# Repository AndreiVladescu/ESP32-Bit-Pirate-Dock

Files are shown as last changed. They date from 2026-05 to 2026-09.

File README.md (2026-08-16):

<div align="center">

# ESP32-Bit-Pirate-Hardware

<a href="https://github.com/geo-tp/ESP32-Bit-Pirate">
  ESP32 Bit Pirate ecosystem banner
</a>

</div>

**ESP32-Bit-Pirate-Dock** is an open-source carrier board for the Espressif ESP32-S3 DevKit, designed to complement the [ESP32-Bit-Pirate](https://github.com/geo-tp/ESP32-Bit-Pirate) firmware by [geo-tp](https://github.com/geo-tp).

It provides level and voltage translation between the 3.3V ESP32-S3 and external peripherals, with support for **1.8V**, **3.3V**, and **5V** operation. See the [Hardware status](#-hardware-status) section for the current revision, and grab the [fabrication files](#-manufacturing-and-assembly) to build your own.

<div align="center">

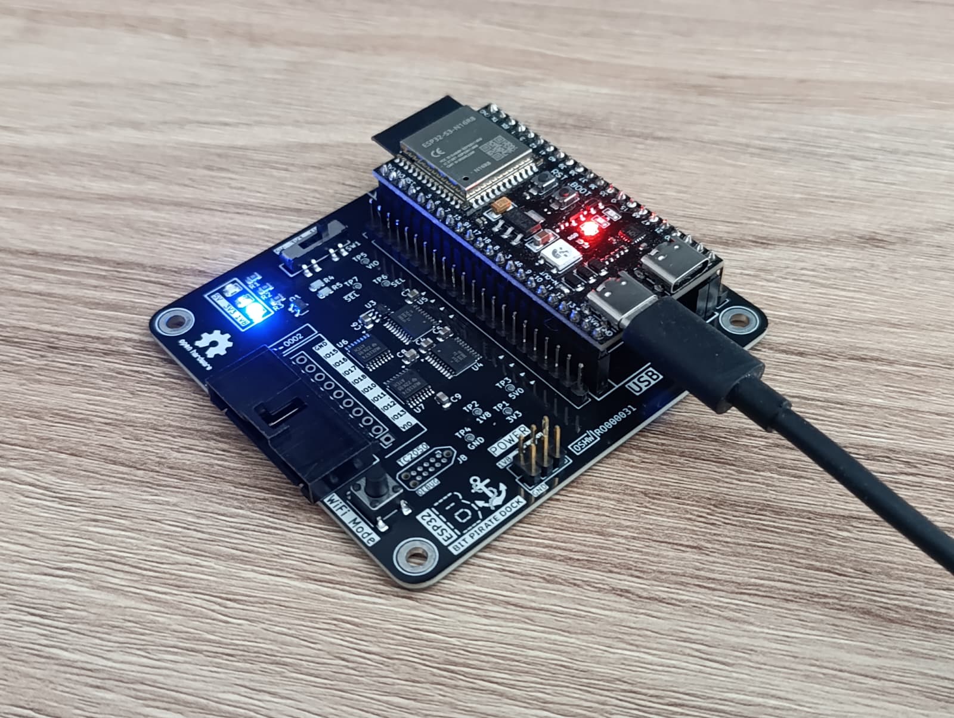
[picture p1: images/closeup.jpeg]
Closeup


</div>

## 🙏 Thanks to PCBWay

A big thank you to [**PCBWay**](https://www.pcbway.com/) for sponsoring and manufacturing the PCBs for this project. Their high-quality fabrication and assembly made bringing this dock to life possible. You can buy the Dock [here](https://www.pcbway.com/project/shareproject/ESP32_Bit_Pirate_Dock_ca02ded7.html) and support the project.

<div align="center">

<a href="https://www.pcbway.com/">
  PCBs manufactured by PCBWay
</a>

</div>

## ✨ Features

- **Level & voltage translation** between the 3.3V ESP32-S3 and external peripherals.
- **Selectable I/O voltage:** 1.8V, 3.3V, and 5V operation.
- **Carrier board** for the original ESP32-S3-DevKitC-1 as well as third-party clones.
- **Designed as a companion** to the [ESP32-Bit-Pirate](https://github.com/geo-tp/ESP32-Bit-Pirate) multi-protocol firmware.
- **Fully open-source hardware** — schematic, PCB layout, gerbers, and BOM included.
- **3D-printable enclosure** — two-piece FDM case provided.

## 📦 Supported Devices

| Device | Notes |
|---|---|
| **ESP32-S3-DevKitC-1** | Genuine Espressif devkit — the reference target for this design. |
| **ESP32-S3 DevKit clones** | Third-party boards work as long as the header pin layout and board dimensions match the official devkit. There is also support for clones which are 2.54mm wider, but you need to measure them to make sure everything will fit|

> [!NOTE]
> This project requires an **ESP32-S3 DevKit to be procured separately by the end user**.

## 🔧 Hardware status

Current hardware revision: **V3**

The markings on the PCB for the serial number `V0-YYWW-XXXXX` are as follows:

- version `0`
- year and week number when these PCBs were produced
- incrementing number of the current batch

An example PCB with these markings would be `V3-2613-00512`, where:

- version number is `3`
- the year is `2026`, and the week is `13`
- this is the `512th` PCB made in that respective week

<div align="center">

Certification mark RO000031

</div>

## 🚀 Getting Started

1. 🛒 **Source an ESP32-S3 DevKit**
   - Buy a genuine board from Espressif or a compatible clone.

2. 🏭 **Fabricate the dock**
   - Send the gerbers in `dock/gerbers/` to your PCB manufacturer of choice.
   - Use `dock/BOM.csv` to source the components for assembly.

3. 🖨️ **Print the enclosure** *(optional)*
   - Print the two-piece case from `dock/3d_models/` on an FDM printer with a 0.4 mm nozzle.

4. 🔌 **Assemble & seat the devkit**
   - Insert the ESP32-S3 DevKit into the headers and select your target I/O voltage (1.8V / 3.3V / 5V).

5. ⚡ **Flash the firmware**
   - Install [ESP32-Bit-Pirate](https://github.com/geo-tp/ESP32-Bit-Pirate) and start probing.

## 📂 Repository contents

- `dock/kicad/` — KiCad design files
- `dock/gerbers/` — PCB fabrication outputs
- `dock/schematic.pdf` — exported schematic reference
- `dock/BOM.csv` — bill of materials
- `dock/3d_models/` — 3D models for the dock and a WIP case
- `c5_adapter/` — KiCad design files for the companion C5 adapter board
- `images/` — presentation images

## 🌐 Open-source scope

This repository open-sources the dock hardware design, including:

- schematic and PCB layout source files
- fabrication outputs
- bill of materials
- project documentation and images included in this repository

## 🧩 Required external parts

This project requires an **ESP32-S3 DevKit to be procured separately by the end user**.

The ESP32-S3 DevKit is a third-party board/module and is **not included** as part of this hardware design repository unless explicitly stated. Vendor silicon, datasheets, trademarks, and separately licensed third-party materials remain the property of their respective owners.

These boards can be acquired through the official Espressif manufacturer and its stores, or through other third-party websites. If not buying a genuine one, make sure the dimensions fit one of the header pins on the board.

## 🛠️ PCB Design

### Top View

<div align="center">

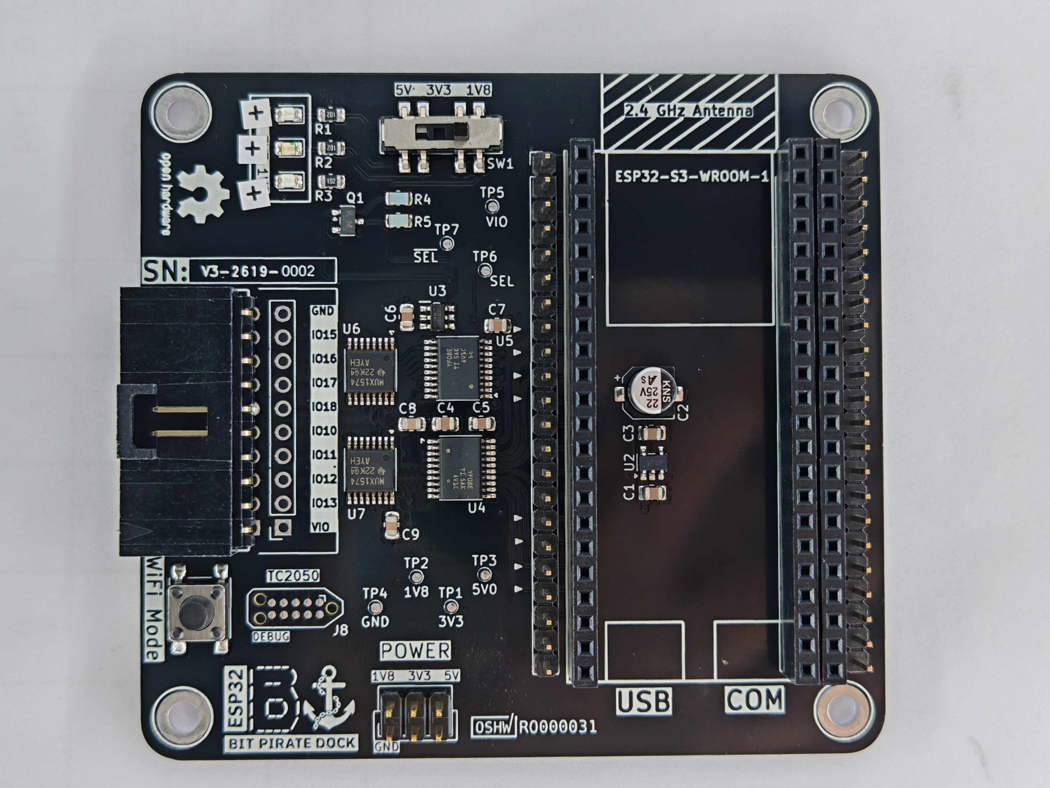
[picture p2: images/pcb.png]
PCB Top


<p>
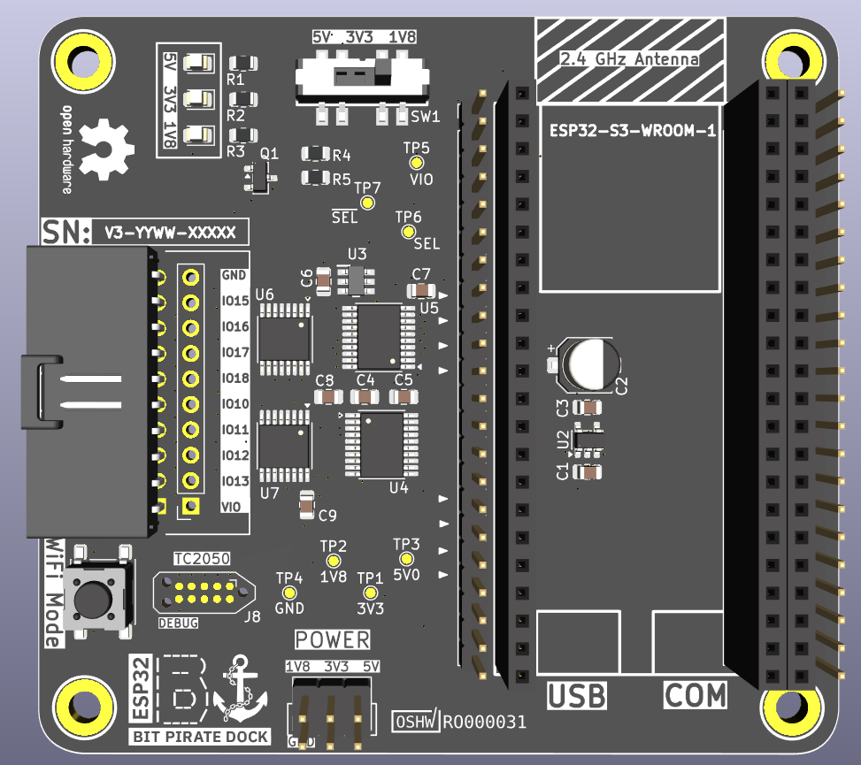
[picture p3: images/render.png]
Front Rendering
  
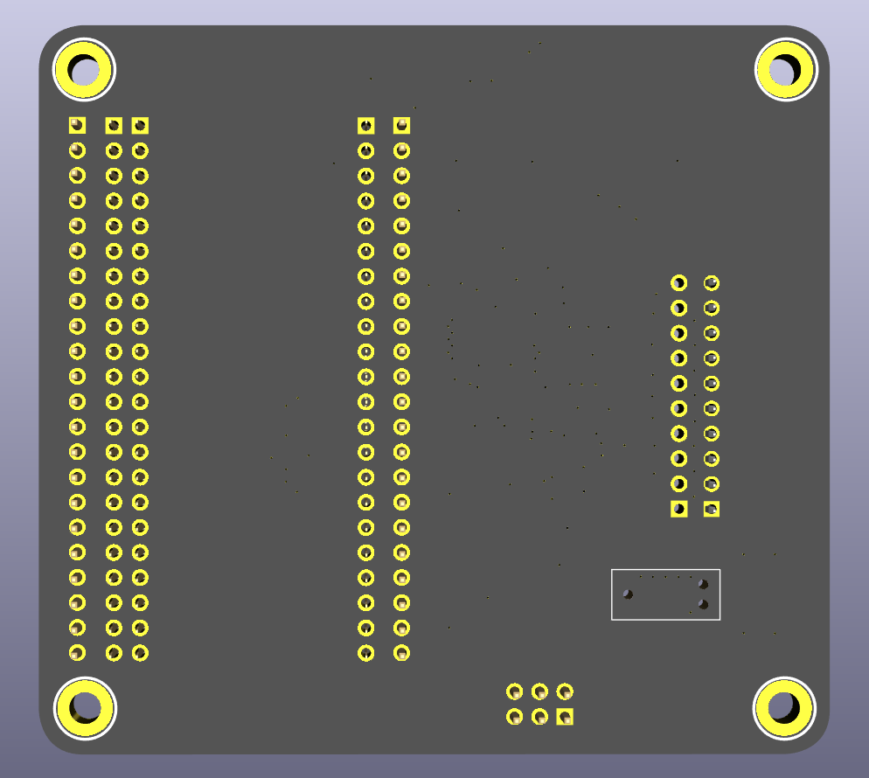
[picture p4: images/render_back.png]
Back Rendering
  
</p>

</div>

## 🏭 Manufacturing and assembly

- To **fabricate the PCB**, use the files in `dock/gerbers/`.
- To **inspect or modify** the design, use the original KiCad source files in `dock/kicad/`.
- To **source components**, use `dock/BOM.csv`.

## 📐 Case Design

The current design uses two pieces, which can be printed using an FDM printer with a 0.4 mm nozzle.

<div align="center">

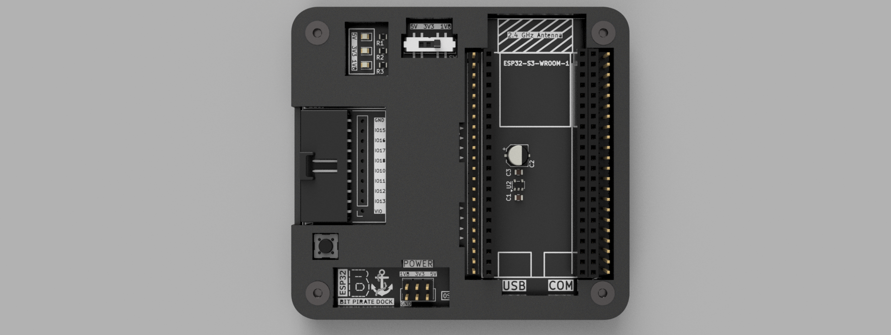
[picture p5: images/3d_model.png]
Case 3D Model


Dock Assembly

</div>

## 🤝 Related Project

This dock is built to complement [**ESP32-Bit-Pirate**](https://github.com/geo-tp/ESP32-Bit-Pirate) by [geo-tp](https://github.com/geo-tp) — an open-source firmware that turns your device into a multi-protocol hacker's tool, inspired by the [Bus Pirate](https://buspirate.com/) project.

## 📜 License

Hardware design files in this repository are licensed under the **CERN-OHL-W-2.0** license. See [LICENSE](LICENSE) for the full license text.

Documentation and images in this repository are licensed under **CC BY 4.0** unless otherwise noted.

Any third-party trademarks, datasheets, and separately licensed materials remain the property of their respective owners.

## ⚠️ Warning

> ⚠️ **Voltage Warning**: External peripherals should only be connected at the **selected translation voltage** (**1.8V**, **3.3V**, or **5V**).
>
> *   Do **not** connect peripherals using other voltage levels — doing so may **damage your ESP32 or the dock**.
> *   Always confirm the selected I/O voltage before powering up connected hardware.
>

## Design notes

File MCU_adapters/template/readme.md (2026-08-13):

Template directory
==================

# Installation

- Copy the **templateAdapters** directory in your **KICAD_USER_TEMPLATE_DIR**
- It will then be displayed in the template list when you create a new project (The template is easy to identify with the Bit Pirate logo).

# How to use
## The schematic
The schematic is divided in 3 parts
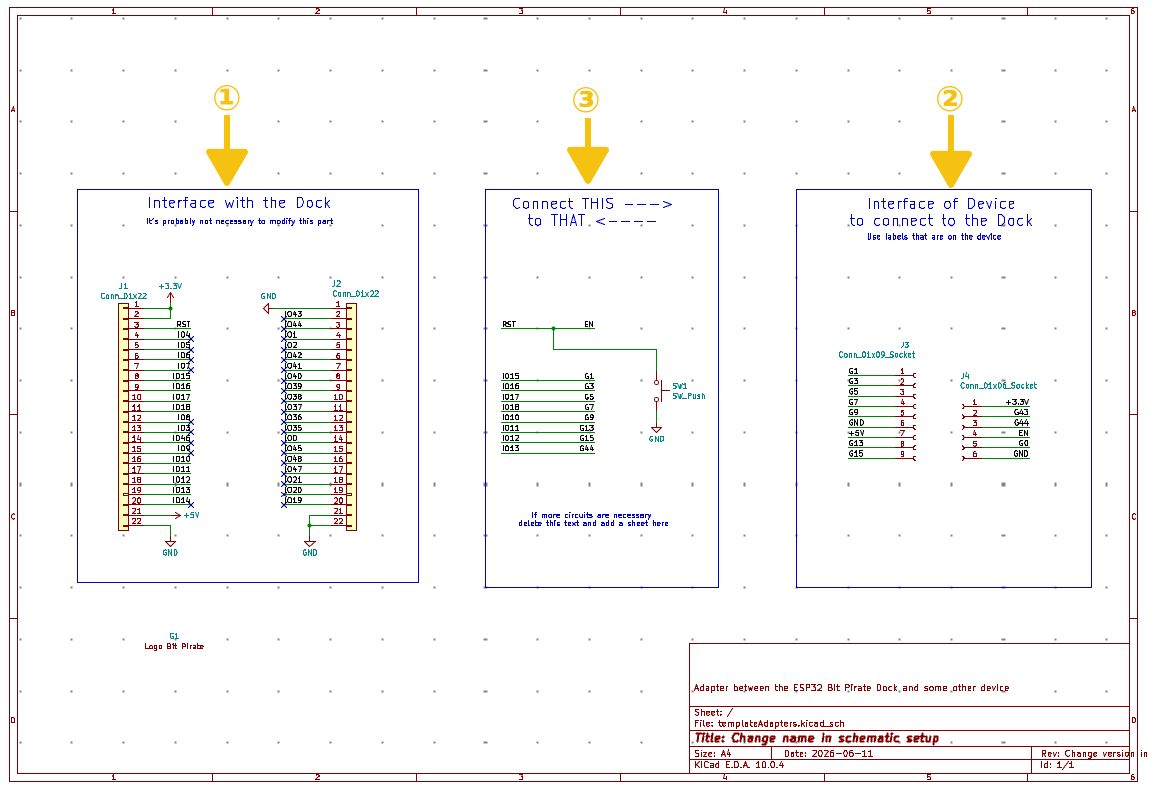
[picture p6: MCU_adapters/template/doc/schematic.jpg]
schematic


1. this part is the interface with the dock. It shows all the IOs that the are exposed to the adapter. By default all the IOs but the 8 ones that are routed to the outside of the dock and the power supplies are tagged as not used. This part is not supposed to be modified.
2. this part is the interface of the device to be connected to the Dock. All the necessary connectors must be added and it is recommanded to use the same label for the IOs as the one used in the device documentation (as long as there is no conflict with the labels of the Dock).
3. this part describes the connexion between the device and the Dock. A least, this part must displays wich IO of the device connects to which IO of the Dock. If some hardware is to be added, it can be drawn in this part or an external sheet can be added in case it is too bulky.

The name of the board and the version number can be changed in Files/Schematic Setup/Text Variables. Their values will be paste to the PCB.  
After the text variables are modified you must: save the schematic, update the PCB, save the PCB, close the PCB, reopen the PCB, the name and version must now be up to date.

## The PCB
By default the PCB is the size of the ESP32-S3 devkit and J1-J2 connectors are locked in place so they will have the right spacing and position.

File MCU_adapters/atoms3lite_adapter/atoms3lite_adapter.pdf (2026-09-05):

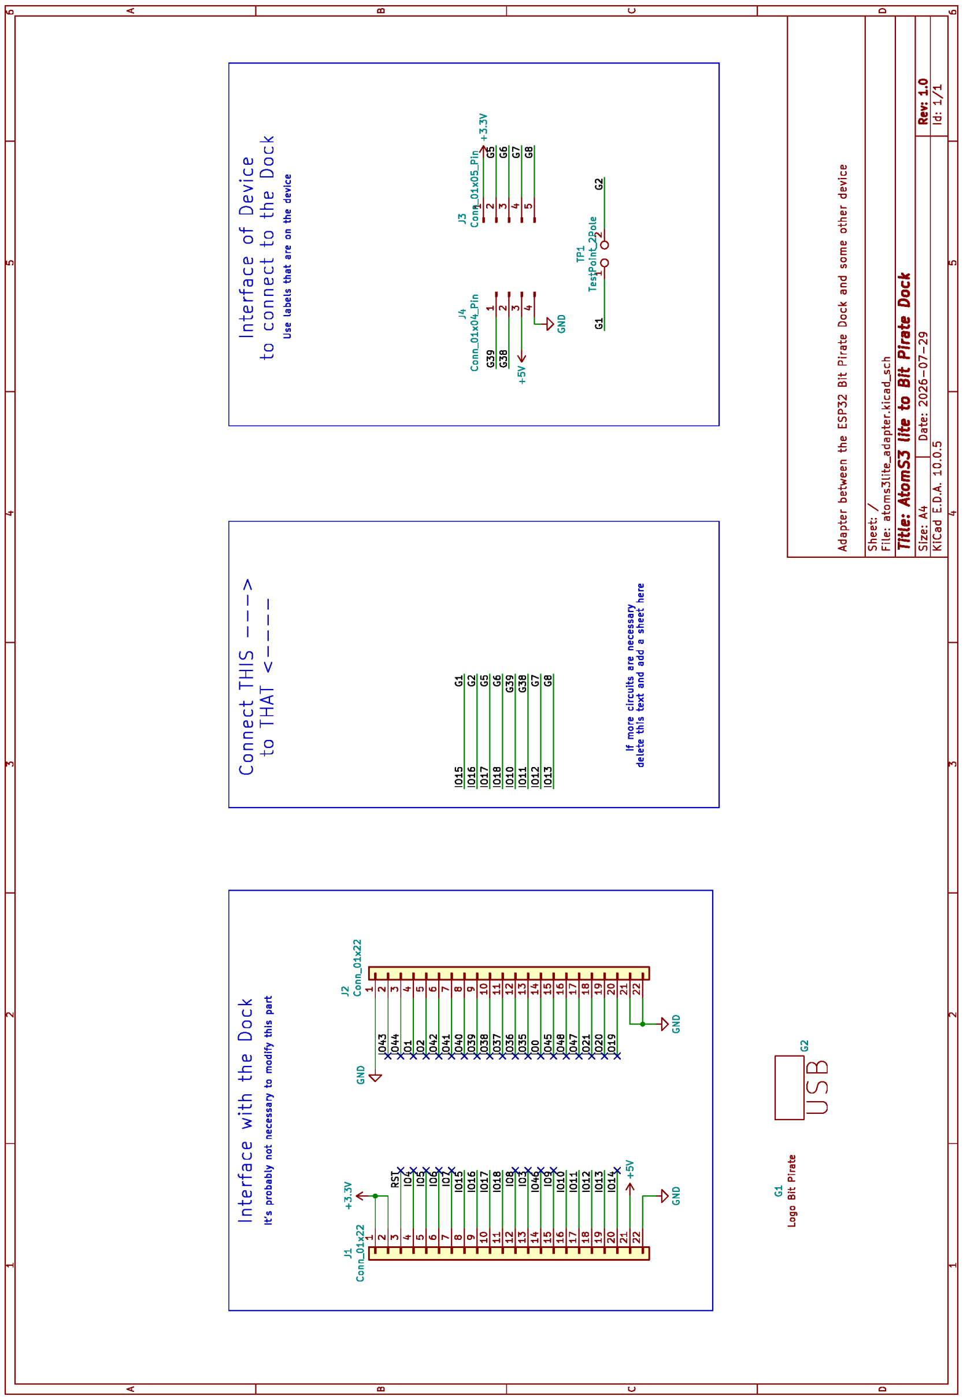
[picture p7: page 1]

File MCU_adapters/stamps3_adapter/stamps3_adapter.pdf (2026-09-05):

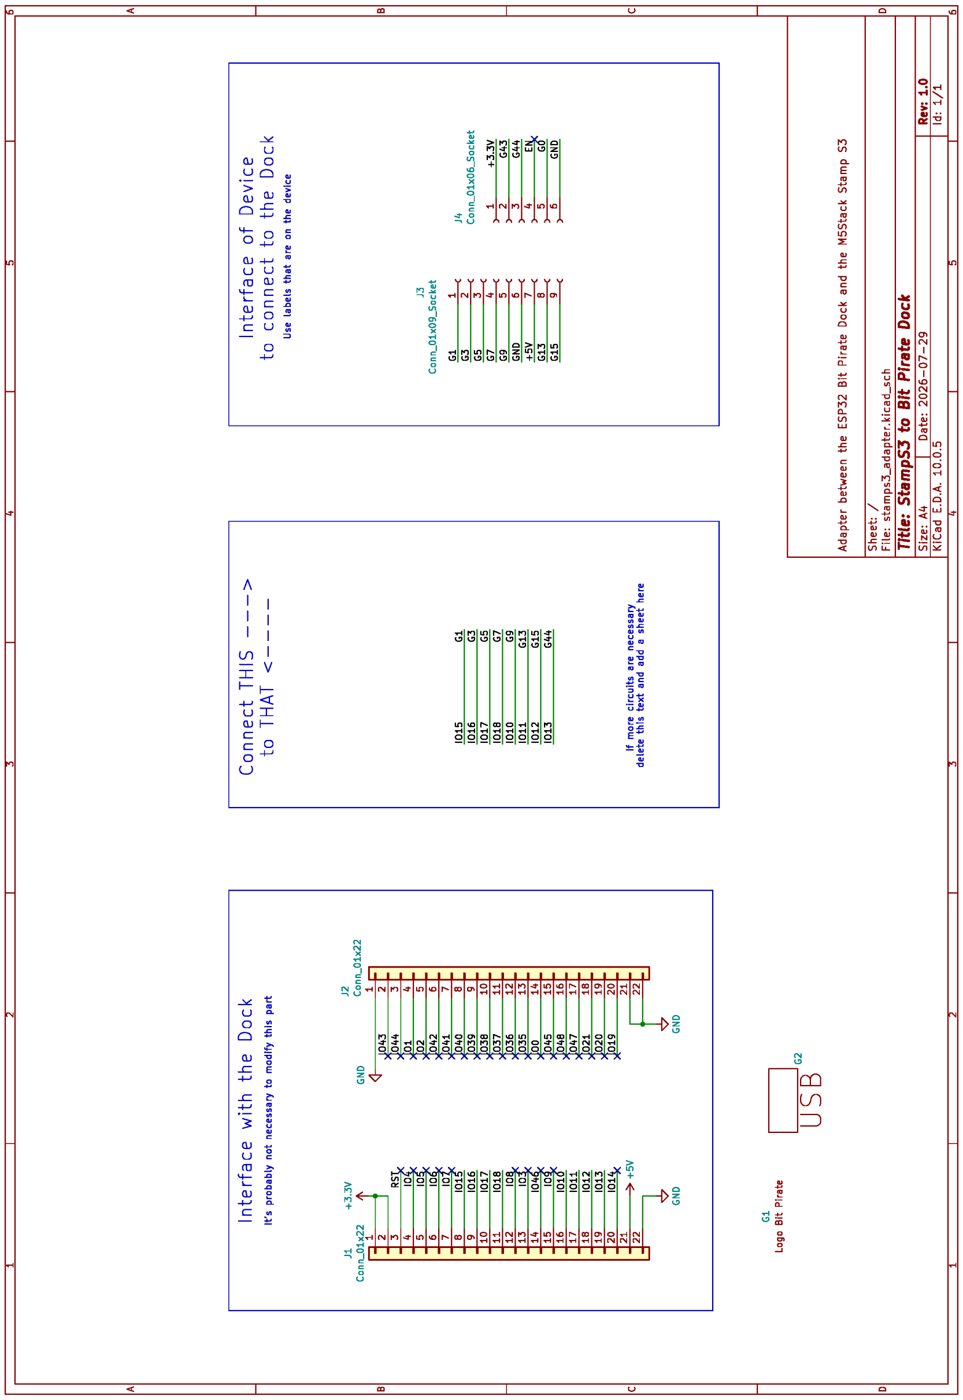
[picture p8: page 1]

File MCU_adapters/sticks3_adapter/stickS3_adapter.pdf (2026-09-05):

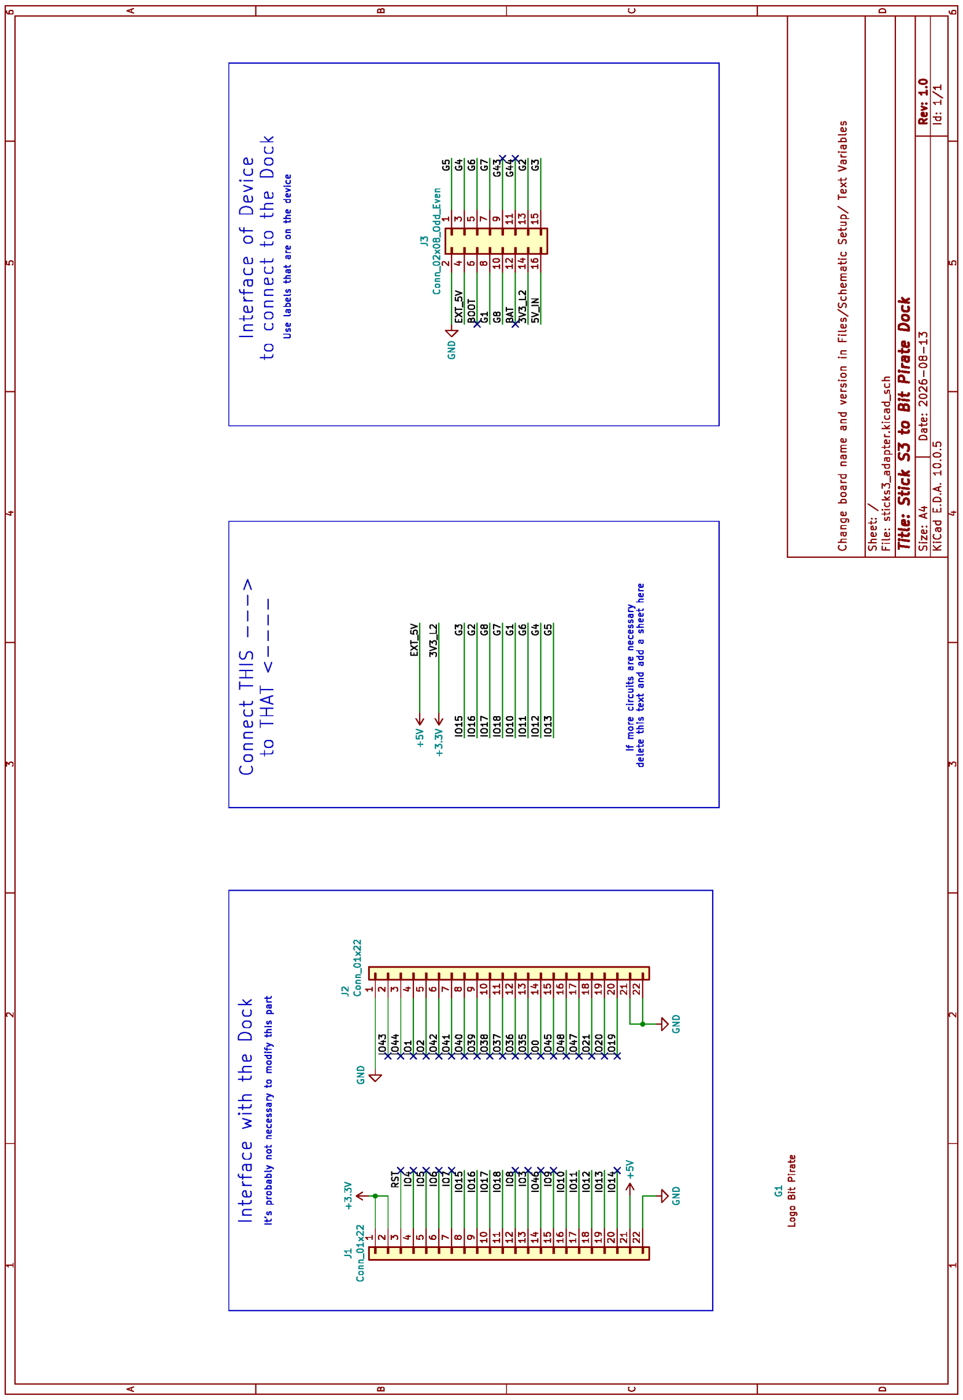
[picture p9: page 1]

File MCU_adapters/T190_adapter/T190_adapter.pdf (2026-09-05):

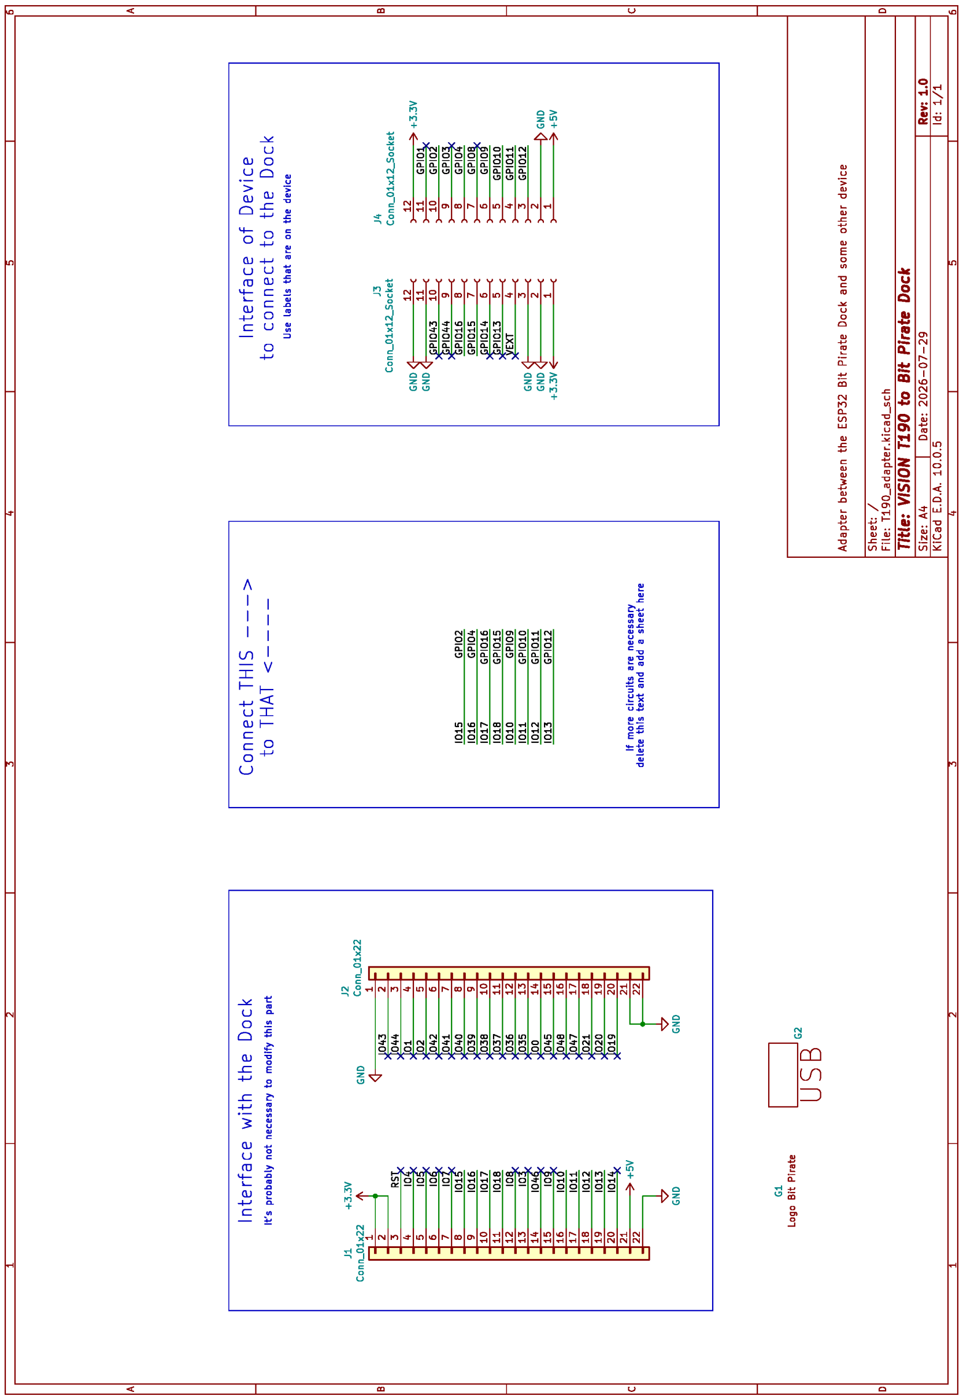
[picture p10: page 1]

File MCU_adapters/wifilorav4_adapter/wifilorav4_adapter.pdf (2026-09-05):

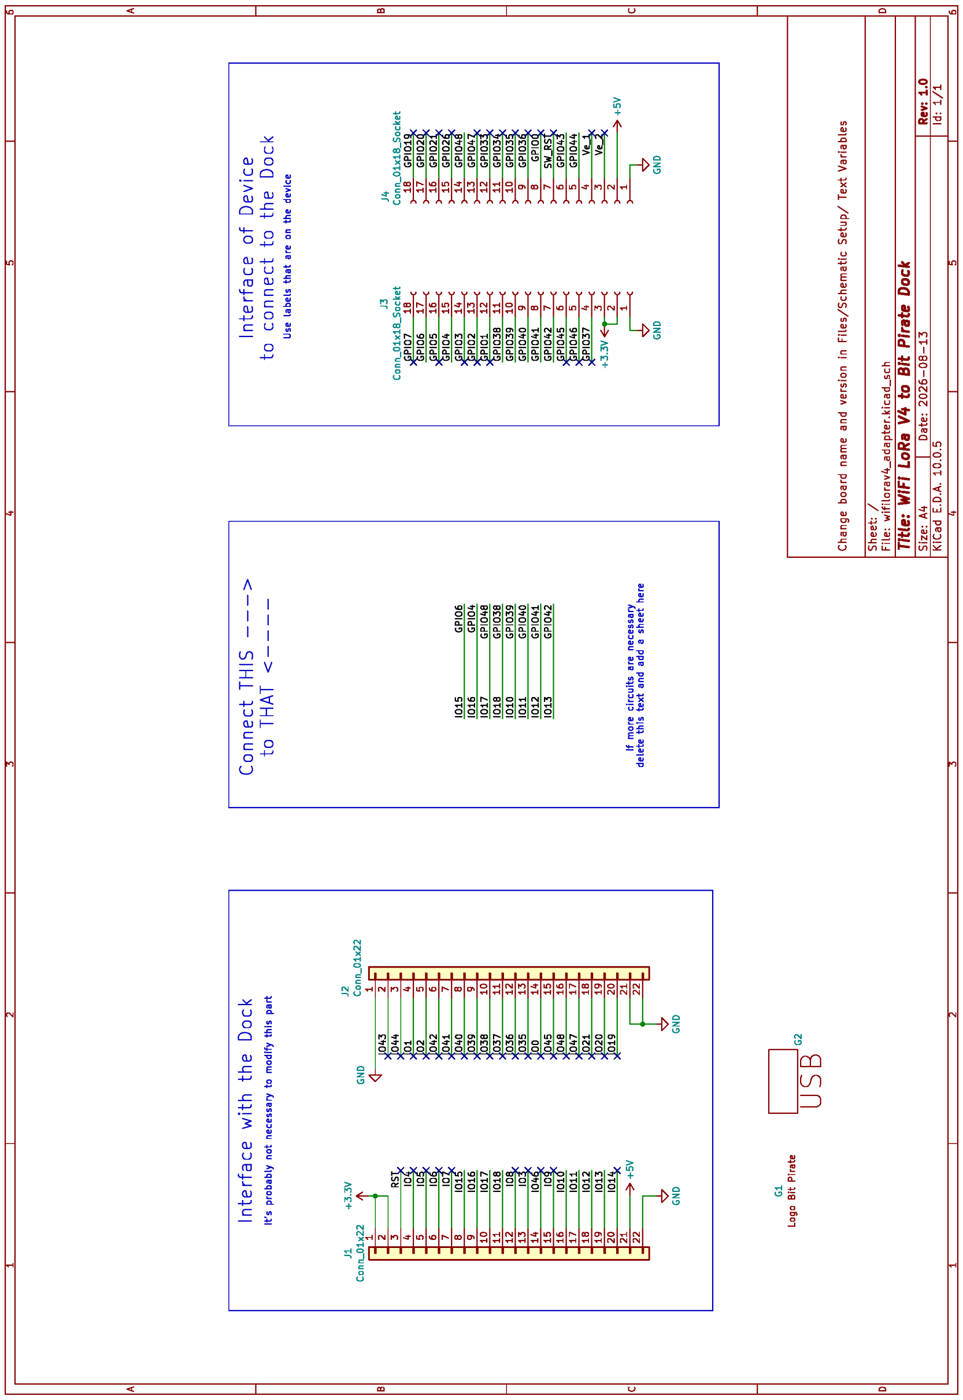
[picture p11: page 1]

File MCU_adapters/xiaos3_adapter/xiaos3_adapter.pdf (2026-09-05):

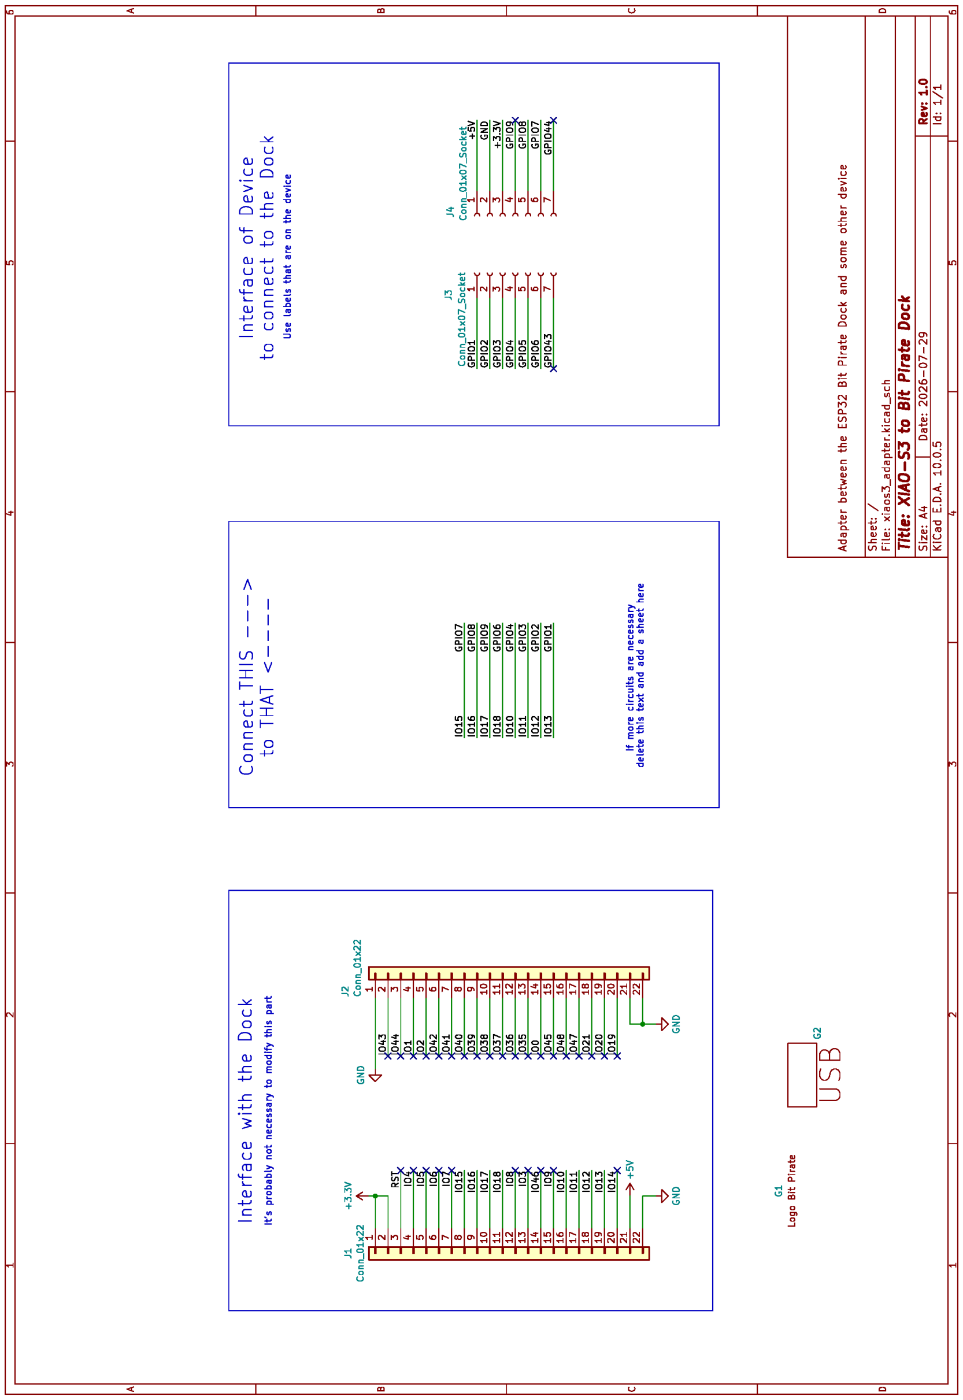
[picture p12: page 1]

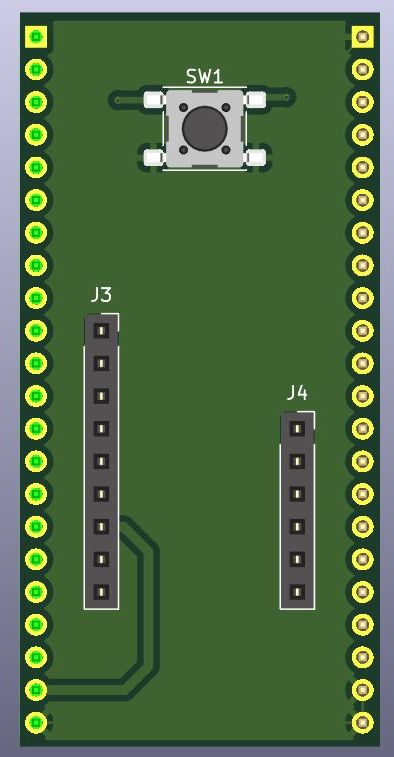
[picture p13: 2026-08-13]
MCU_adapters/template/templateAdapters/meta/board.jpg

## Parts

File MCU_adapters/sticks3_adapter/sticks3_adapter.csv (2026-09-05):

Reference | Qty | Value | DNP | Exclude from BOM | Exclude from Board | Footprint | Datasheet
G1 | 1 |  |  |  |  | logo:logoBP
J1,J2 | 2 | Conn_01x22 |  |  |  | Connector_PinHeader_2.54mm:PinHeader_1x22_P2.54mm_Vertical
J3 | 1 | Conn_02x08_Odd_Even |  |  |  | Connector_PinHeader_2.54mm:PinHeader_2x08_P2.54mm_Horizontal

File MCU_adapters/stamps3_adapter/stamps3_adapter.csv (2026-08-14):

Reference | Qty | Value | DNP | Exclude from BOM | Exclude from Board | Footprint | Datasheet
G1 | 1 |  |  |  |  | logo:logoBP
J1,J2 | 2 | Conn_01x22 |  |  |  | Connector_PinHeader_2.54mm:PinHeader_1x22_P2.54mm_Vertical
J3 | 1 | Conn_01x09_Socket |  |  |  | Connector_PinSocket_2.54mm:PinSocket_1x09_P2.54mm_Vertical
J4 | 1 | Conn_01x06_Socket |  |  |  | Connector_PinSocket_2.54mm:PinSocket_1x06_P2.54mm_Vertical

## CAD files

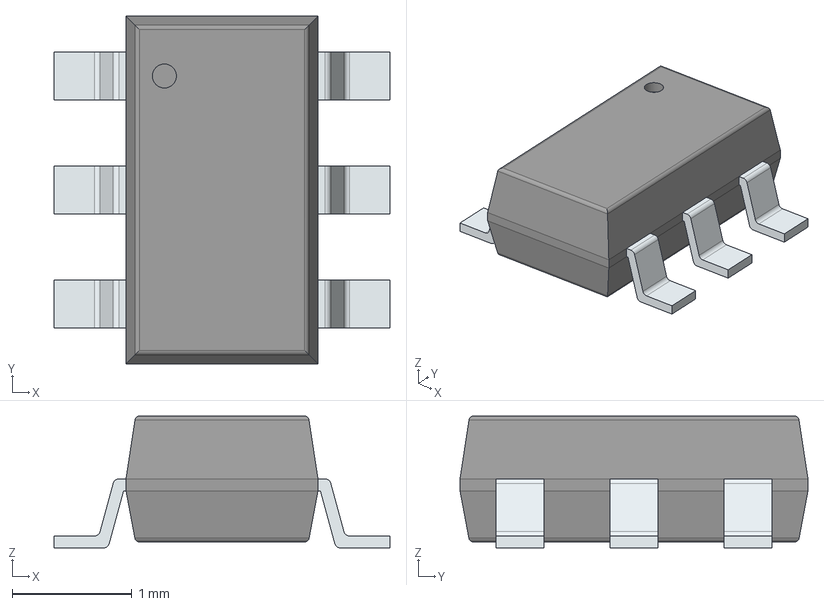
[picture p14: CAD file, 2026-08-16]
device_adapters/c5_adapter/3d_models/TLV6700DDCR.stp
2.80 x 2.90 x 1.10 mm
PinsArrayLR

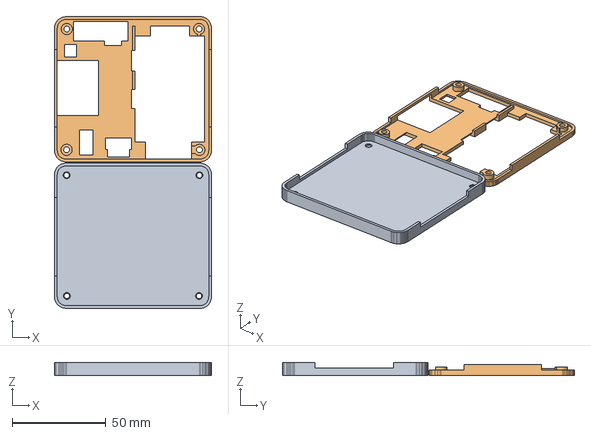
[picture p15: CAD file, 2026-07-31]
dock/3d_models/dock_case_with_logo.step
84.0 x 156.1 x 7.01 mm
Bottom Case
Top Case

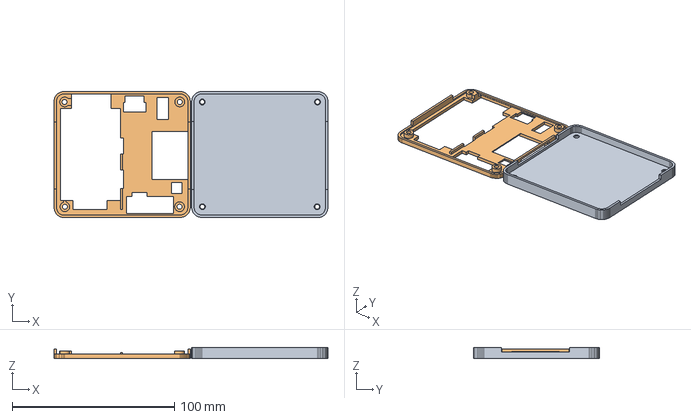
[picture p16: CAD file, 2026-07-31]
dock/3d_models/dock_case_no_logo.step
168.8 x 77.8 x 7.01 mm
Bottom Case
Top Case

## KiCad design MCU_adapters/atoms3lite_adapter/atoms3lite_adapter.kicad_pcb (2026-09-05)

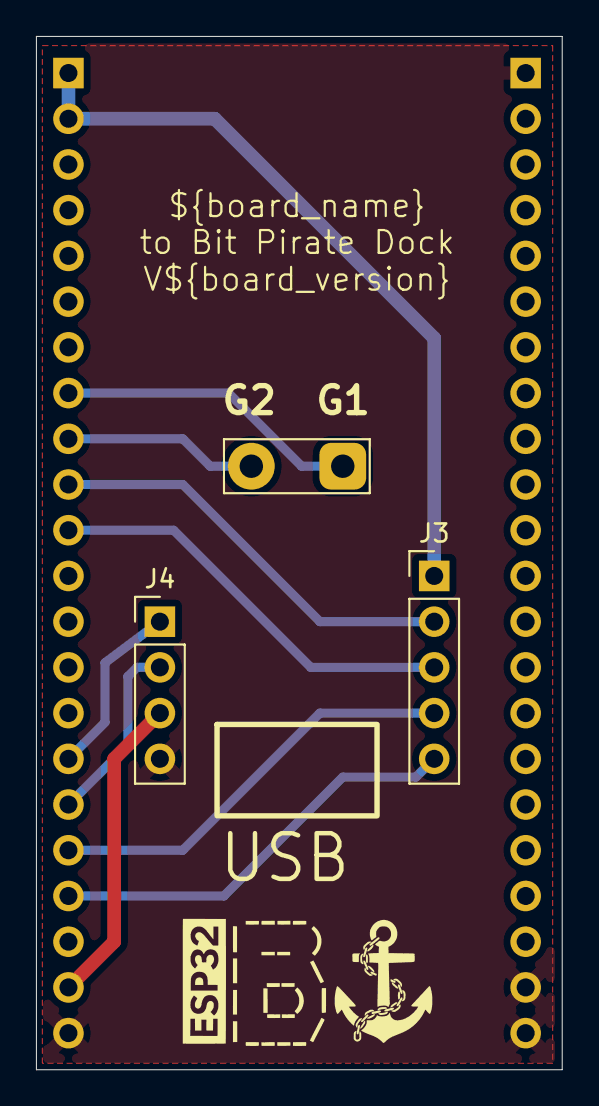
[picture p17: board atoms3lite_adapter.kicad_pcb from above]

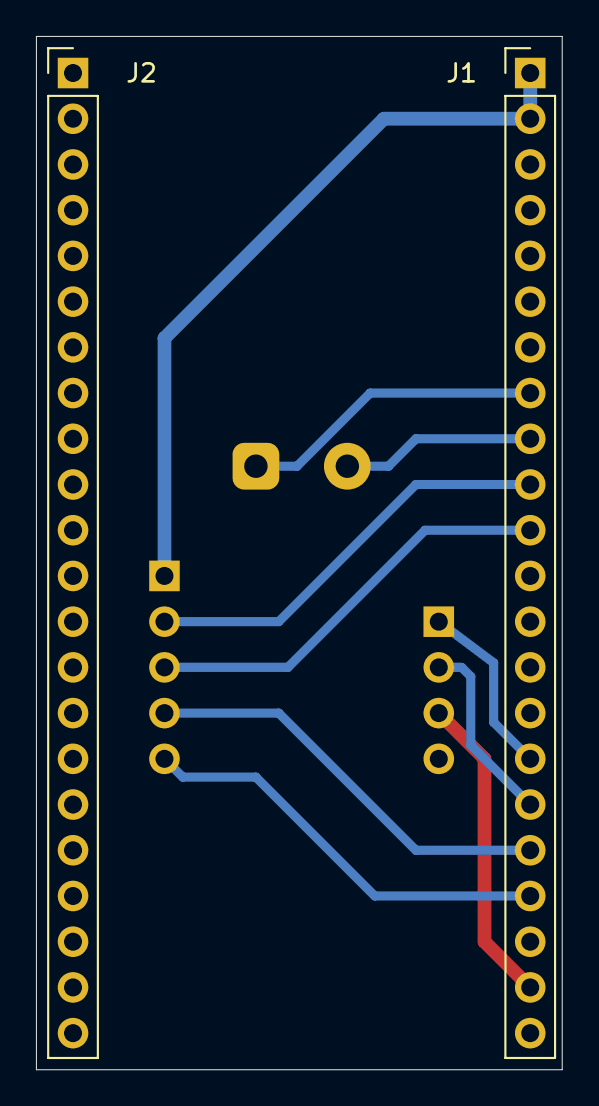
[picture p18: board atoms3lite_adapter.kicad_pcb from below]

Board: 2 copper layers, 29.2 x 57.4 mm, 7 parts (2 on the bottom side), 11 nets.

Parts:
G1: logoBP
G2: LOGO_USB
J1, J2: Conn_01x22; PinHeader_1x22_P2.54mm_Vertical
J3: Conn_01x05_Pin; PinHeader_1x05_P2.54mm_Vertical
J4: Conn_01x04_Pin; PinHeader_1x04_P2.54mm_Vertical
TP1: TestPoint_2Pole; TestPoint_2Pads_Pitch5.08mm_Drill1.3mm

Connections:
+3.3V: J1.1, J1.2, J3.1
+5V: J1.21, J4.3
/G1: J1.8, TP1.1
/G2: J1.9, TP1.2
/G5: J1.10, J3.2
/G6: J1.11, J3.3
/G7: J1.18, J3.4
/G8: J1.19, J3.5
/G38: J1.17, J4.2
/G39: J1.16, J4.1
GND: J1.22, J2.1, J2.21, J2.22, J4.4

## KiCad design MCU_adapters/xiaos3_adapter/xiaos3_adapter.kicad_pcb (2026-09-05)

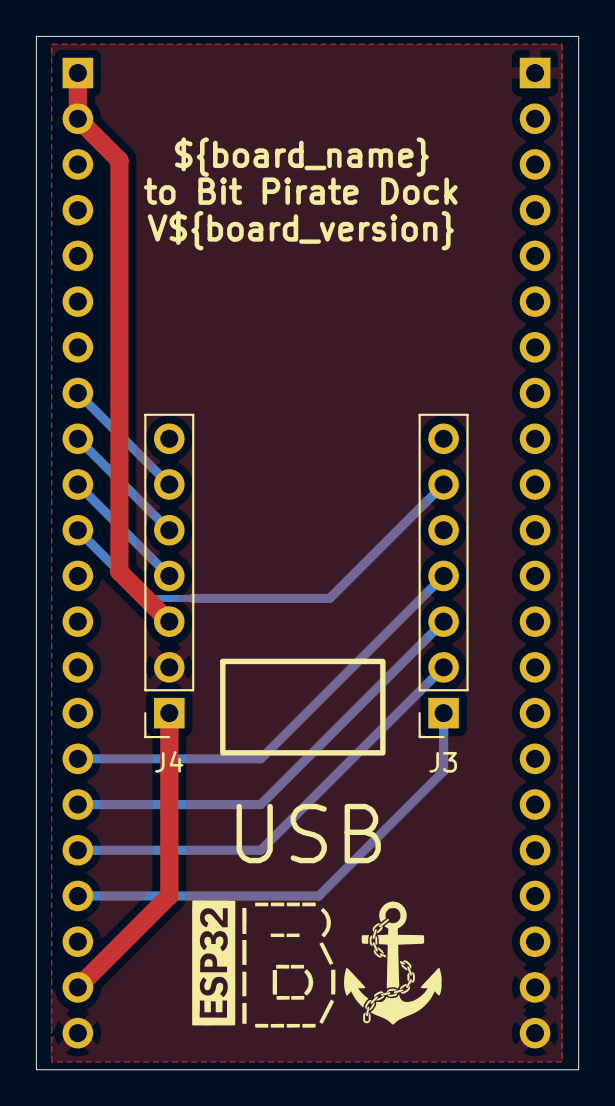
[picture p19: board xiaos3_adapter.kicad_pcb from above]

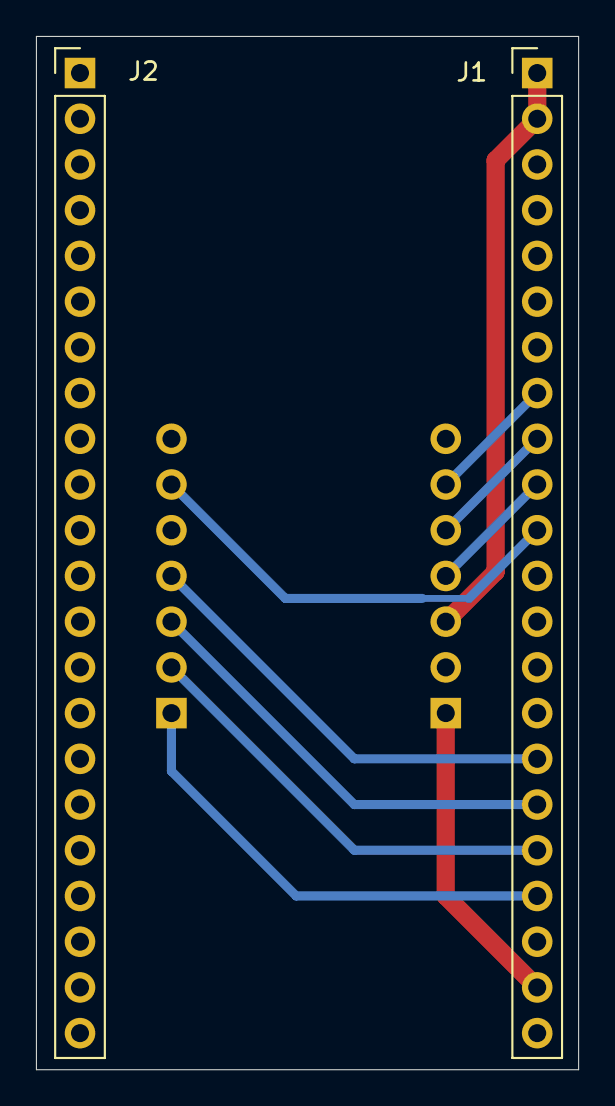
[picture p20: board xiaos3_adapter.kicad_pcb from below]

Board: 2 copper layers, 30.1 x 57.4 mm, 6 parts (2 on the bottom side), 11 nets.

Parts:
G1: logoBP
G2: LOGO_USB
J1, J2: Conn_01x22; PinHeader_1x22_P2.54mm_Vertical
J3, J4: Conn_01x07_Socket; PinSocket_1x07_P2.54mm_Vertical

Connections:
+3.3V: J1.1, J1.2, J4.3
+5V: J1.21, J4.1
/GPIO1: J1.19, J3.1
/GPIO2: J1.18, J3.2
/GPIO3: J1.17, J3.3
/GPIO4: J1.16, J3.4
/GPIO6: J1.11, J3.6
/GPIO7: J1.8, J4.6
/GPIO8: J1.9, J4.5
/GPIO9: J1.10, J4.4
GND: J1.22, J2.1, J2.21, J2.22, J4.2

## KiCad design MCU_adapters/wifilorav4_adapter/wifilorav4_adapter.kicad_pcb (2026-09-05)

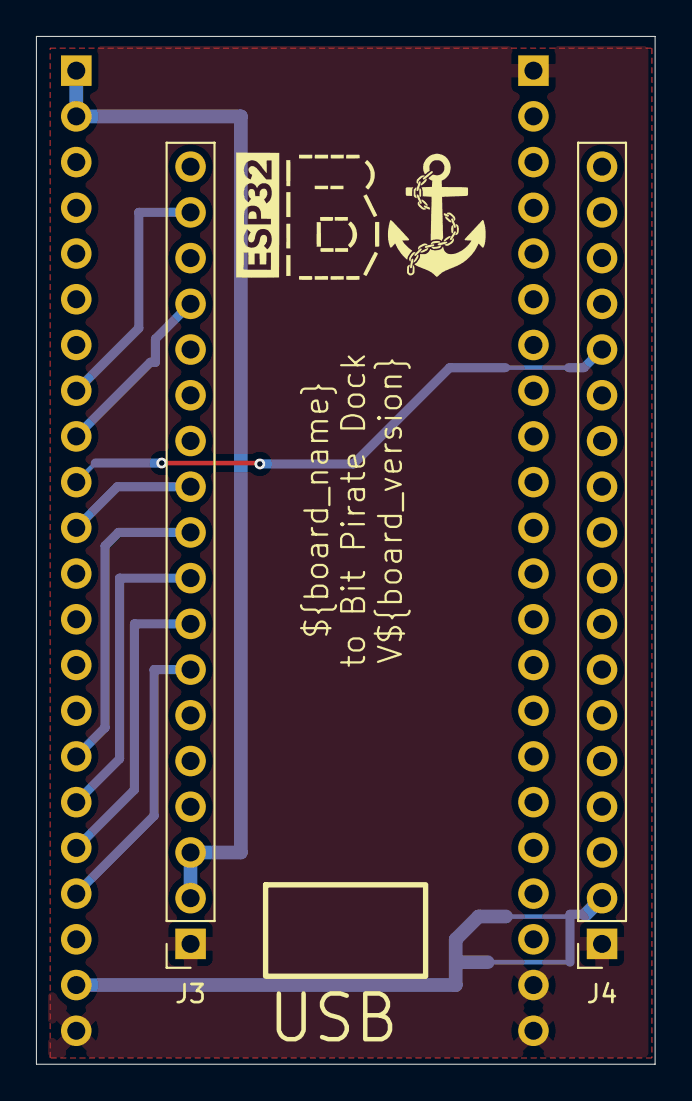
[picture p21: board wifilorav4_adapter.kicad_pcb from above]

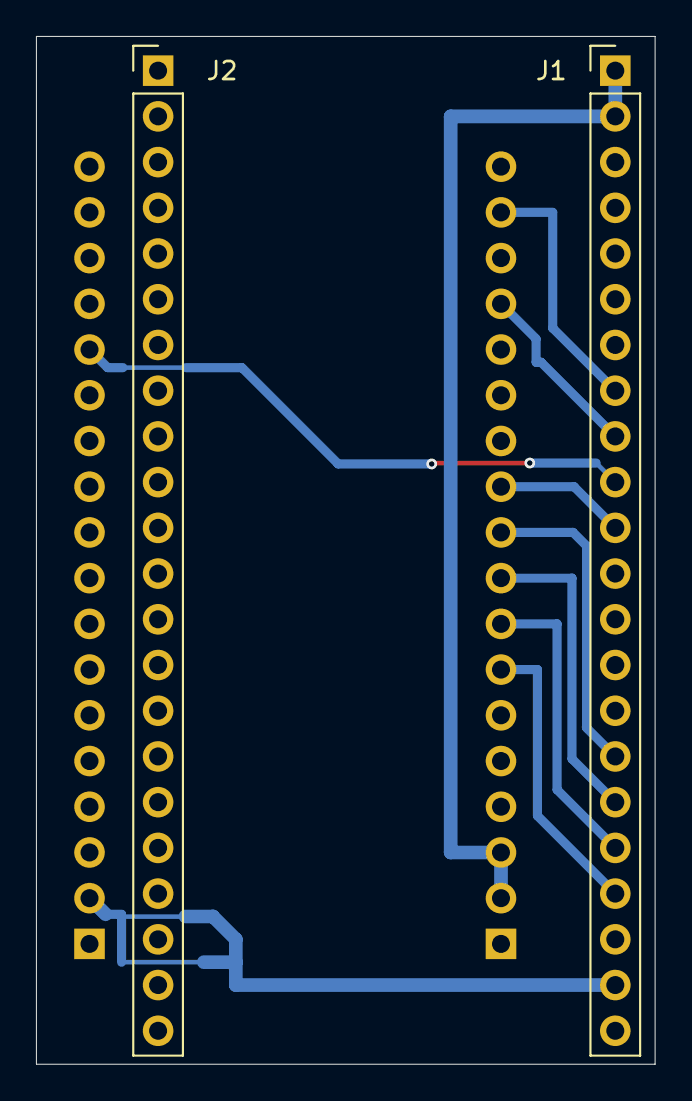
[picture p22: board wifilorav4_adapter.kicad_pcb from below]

Board: 2 copper layers, 34.4 x 57.1 mm, 6 parts (2 on the bottom side), 11 nets.

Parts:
G1: logoBP
G2: LOGO_USB
J1, J2: Conn_01x22; PinHeader_1x22_P2.54mm_Vertical
J3, J4: Conn_01x18_Socket; PinSocket_1x18_P2.54mm_Vertical

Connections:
+3.3V: J1.1, J1.2, J3.2, J3.3
+5V: J1.21, J4.2
/GPIO4: J1.9, J3.15
/GPIO6: J1.8, J3.17
/GPIO38: J1.11, J3.11
/GPIO39: J1.16, J3.10
/GPIO40: J1.17, J3.9
/GPIO41: J1.18, J3.8
/GPIO42: J1.19, J3.7
/GPIO48: J1.10, J4.14
GND: J1.22, J2.1, J2.21, J2.22, J3.1, J4.1

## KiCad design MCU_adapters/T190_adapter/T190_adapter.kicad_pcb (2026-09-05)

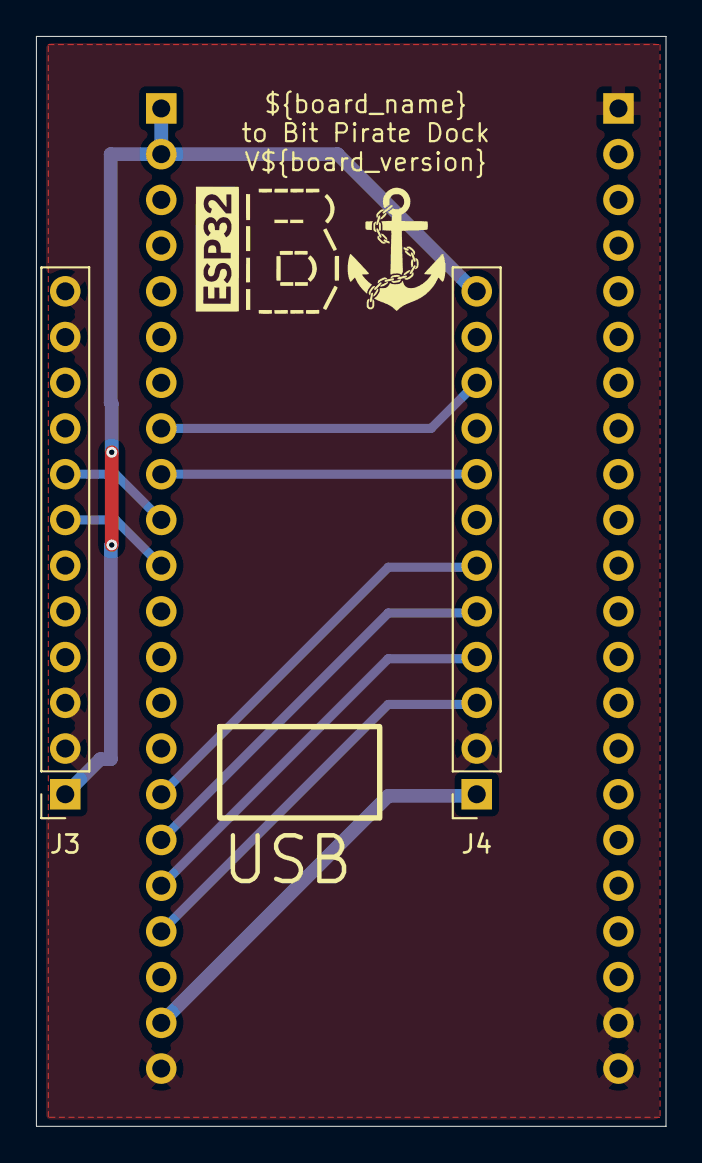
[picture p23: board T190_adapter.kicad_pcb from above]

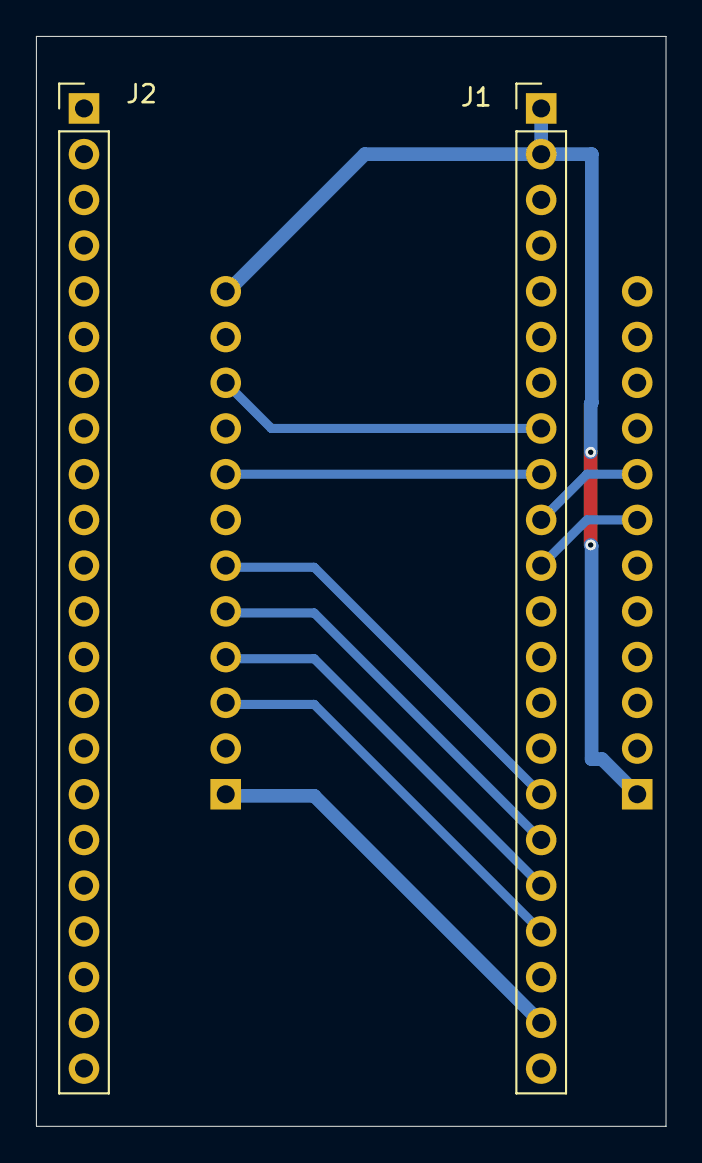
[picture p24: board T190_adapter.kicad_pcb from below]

Board: 2 copper layers, 35.0 x 60.6 mm, 6 parts (2 on the bottom side), 11 nets.

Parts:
G1: logoBP
G2: LOGO_USB
J1, J2: Conn_01x22; PinHeader_1x22_P2.54mm_Vertical
J3, J4: Conn_01x12_Socket; PinSocket_1x12_P2.54mm_Vertical

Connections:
+3.3V: J1.1, J1.2, J3.1, J4.12
+5V: J1.21, J4.1
/GPIO2: J1.8, J4.10
/GPIO4: J1.9, J4.8
/GPIO9: J1.16, J4.6
/GPIO10: J1.17, J4.5
/GPIO11: J1.18, J4.4
/GPIO12: J1.19, J4.3
/GPIO15: J1.11, J3.7
/GPIO16: J1.10, J3.8
GND: J1.22, J2.1, J2.21, J2.22, J3.2, J3.3, J3.11, J3.12, J4.2

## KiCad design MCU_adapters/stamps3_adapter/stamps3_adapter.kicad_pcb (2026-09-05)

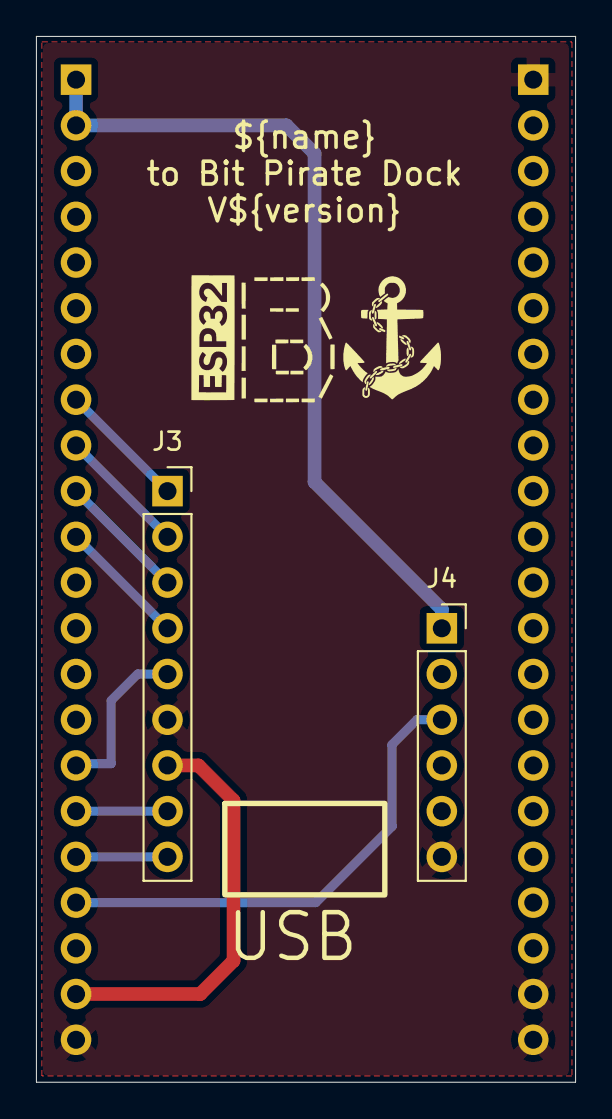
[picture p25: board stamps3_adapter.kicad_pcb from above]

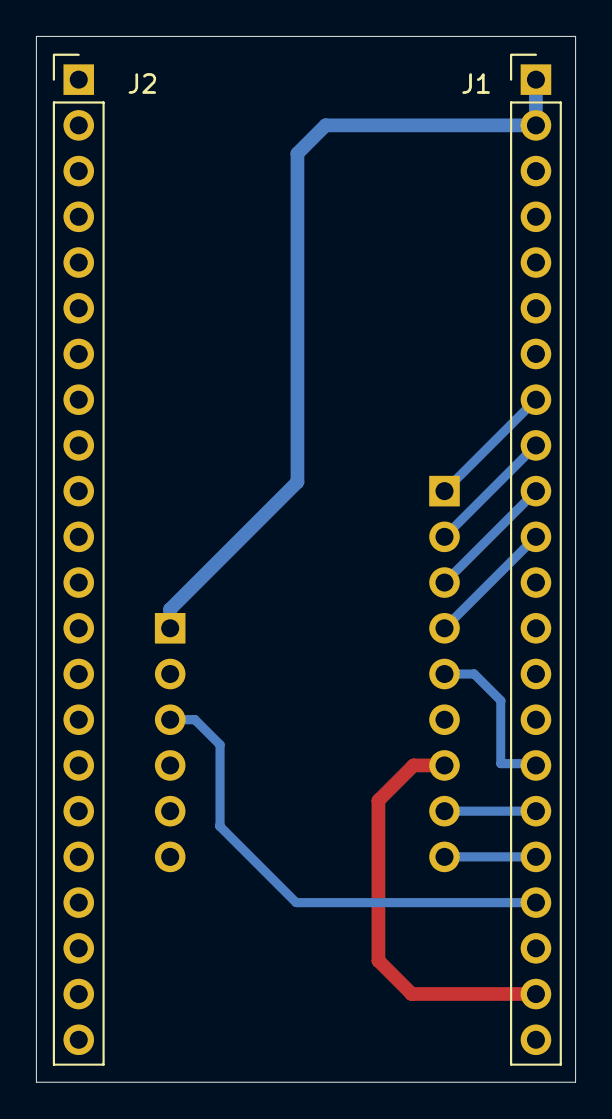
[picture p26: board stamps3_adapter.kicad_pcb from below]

Board: 2 copper layers, 30.0 x 58.1 mm, 6 parts (2 on the bottom side), 11 nets.

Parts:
G1: logoBP
G2: LOGO_USB
J1, J2: Conn_01x22; PinHeader_1x22_P2.54mm_Vertical
J3: Conn_01x09_Socket; PinSocket_1x09_P2.54mm_Vertical
J4: Conn_01x06_Socket; PinSocket_1x06_P2.54mm_Vertical

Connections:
+3.3V: J1.1, J1.2, J4.1
+5V: J1.21, J3.7
/G1: J1.8, J3.1
/G3: J1.9, J3.2
/G5: J1.10, J3.3
/G7: J1.11, J3.4
/G9: J1.16, J3.5
/G13: J1.17, J3.8
/G15: J1.18, J3.9
/G44: J1.19, J4.3
GND: J1.22, J2.1, J2.21, J2.22, J3.6, J4.6

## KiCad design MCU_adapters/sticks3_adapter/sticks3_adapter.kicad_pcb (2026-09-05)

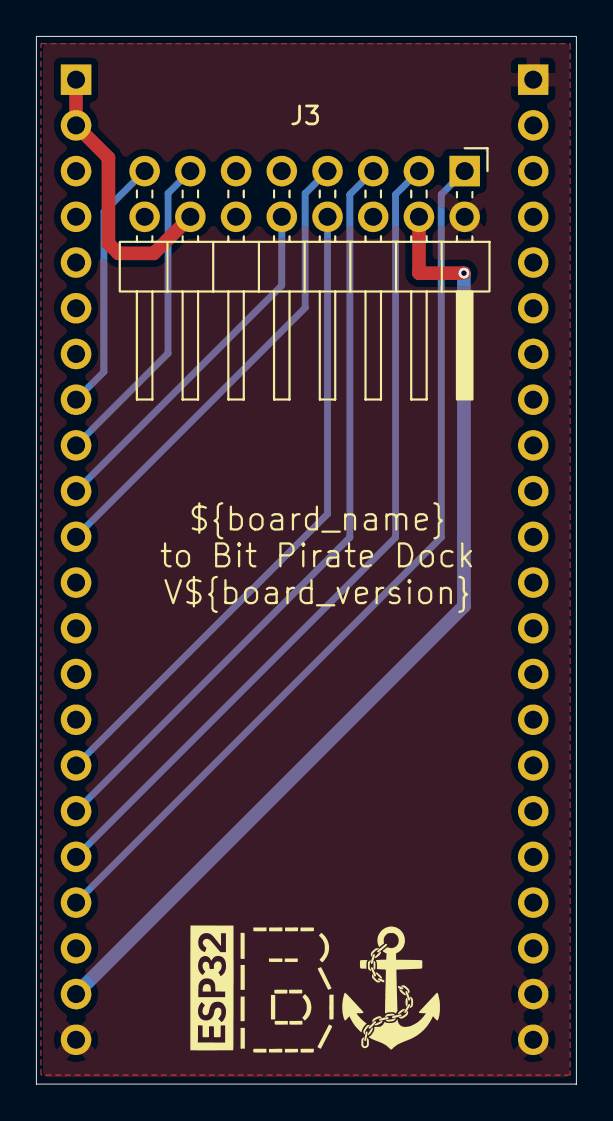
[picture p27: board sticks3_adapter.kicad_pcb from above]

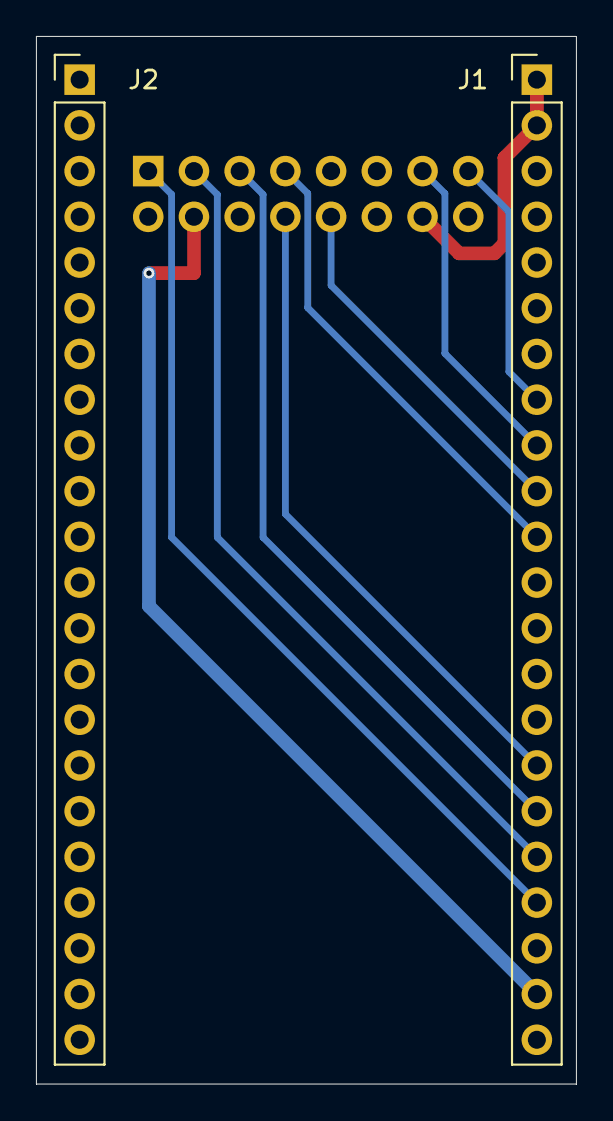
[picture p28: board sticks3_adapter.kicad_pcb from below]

Board: 2 copper layers, 30.0 x 58.2 mm, 4 parts (2 on the bottom side), 11 nets.

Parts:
G1: logoBP
J1, J2: Conn_01x22; PinHeader_1x22_P2.54mm_Vertical
J3: Conn_02x08_Odd_Even; PinHeader_2x08_P2.54mm_Horizontal

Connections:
+3.3V: J1.1, J1.2, J3.14
+5V: J1.21, J3.4
/G1: J1.16, J3.8
/G2: J1.9, J3.13
/G3: J1.8, J3.15
/G4: J1.18, J3.3
/G5: J1.19, J3.1
/G6: J1.17, J3.5
/G7: J1.11, J3.7
/G8: J1.10, J3.10
GND: J1.22, J2.1, J2.21, J2.22, J3.2

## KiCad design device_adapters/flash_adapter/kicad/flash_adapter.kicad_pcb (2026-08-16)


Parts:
C1: 100n; C_0805_2012Metric
D1, D2, D3: GREEN; LED_0805_2012Metric
D4: BLUE; LED_0805_2012Metric
J1: Conn_01x10; PinSocket_1x10_P2.54mm_Horizontal
J2: Conn_01x10; PinSocket_1x10_P2.54mm_Vertical
J3: DS1044-160G; CONNFLY_DS1044-160G
R1, R4, R7, R8: 1k; R_0805_2012Metric
R2, R3, R5, R6: 10k; R_0805_2012Metric

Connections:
CS#1: D2.1 (K), J1.3, J2.3, J3.1, R5.2
CS#2: D3.1 (K), J1.7, J2.7, J3.5, R6.2
GND: C1.2, D1.1 (K), D4.1 (K), J1.10, J2.10, J3.4, J3.8
HOLD: J1.4, J2.4, J3.11, J3.15, R3.1
IO13: J1.2, J2.2, R8.1
MISO: J1.9, J2.9, J3.9, J3.13
MOSI: J1.6, J2.6, J3.2, J3.6
unnamed: D1.2 (A), R1.2
unnamed: D2.2 (A), R4.2
unnamed: D3.2 (A), R7.2
unnamed: D4.2 (A), R8.2
SCLK: J1.8, J2.8, J3.10, J3.14
VIO_{DOCK}: C1.1, J1.1, J2.1, J3.12, J3.16, R1.1, R2.2, R3.2, R4.1, R5.1, R6.1, R7.1
WP: J1.5, J2.5, J3.3, J3.7, R2.1

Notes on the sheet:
Bottom Half
Top Half


Board: 2 copper layers, 41.2 x 43.5 mm, 16 parts (0 on the bottom side), 14 nets.

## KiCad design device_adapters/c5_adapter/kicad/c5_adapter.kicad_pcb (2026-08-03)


Board: 2 copper layers, 50.0 x 45.0 mm, 6 parts (0 on the bottom side), 27 nets.

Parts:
J1: Conn_01x10; PinSocket_1x10_P2.54mm_Horizontal
J3, J6: Conn_01x16; PinHeader_1x16_P2.54mm_Vertical
J4, J5: Conn_01x16; PinSocket_1x16_P2.54mm_Vertical
SW1: MK-12C02-G020; SW-SMD_MK-12C02-G020

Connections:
+3V3: J3.1, J4.1, SW1.2
+5V: J3.14, J4.14
BOOT: J1.3, J5.11, J6.11
GND: J1.10, J3.15, J4.15, J5.1, J5.12, J5.15, J6.1, J6.12, J6.15, SW1.4, SW1.5, SW1.6, SW1.7
IO6: J1.6, J3.10, J4.10
IO8: J1.7, J5.9, J6.9
IO9: J1.8, J5.8, J6.8
IO10: J1.9, J5.7, J6.7
unnamed: J3.3, J4.3
unnamed: J3.4, J4.4
unnamed: J3.5, J4.5
unnamed: J3.6, J4.6
unnamed: J3.7, J4.7
unnamed: J3.8, J4.8
unnamed: J3.9, J4.9
unnamed: J3.11, J4.11
unnamed: J3.12, J4.12
unnamed: J3.13, J4.13
unnamed: J5.4, J6.4
unnamed: J5.5, J6.5
unnamed: J5.6, J6.6
unnamed: J5.13, J6.13
unnamed: J5.14, J6.14
RST: J1.2, J3.2, J4.2
UART_RX: J1.5, J5.3, J6.3
UART_TX: J1.4, J5.2, J6.2
VIO_{DOCK}: J1.1, SW1.1

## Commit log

2026-05-08 Changed logo
    [ESP32-Bus-Pirate-Dock.kicad_pcb]
2026-05-08 Added new name for kicad project
    [ESP32-Bit-Pirate.kicad_pcb, ESP32-Bit-Pirate.kicad_sch, voltage_level_translator.kicad_sch]
2026-05-17 Updated C5 schematic
    [c5_adapter.kicad_pcb, c5_adapter.kicad_sch]
2026-05-17 Added SPDT switch
    [c5_adapter.kicad_sch]
2026-05-17 Initial PCB placement
    [c5_adapter.kicad_pcb, c5_adapter.kicad_sch]
2026-05-18 Updated c5 adapter PCB placement
    [c5_adapter.kicad_pcb, c5_adapter.kicad_sch]
2026-05-18 Updated silkscreen on C5 adapter
    [c5_adapter.kicad_pcb, c5_adapter.kicad_sch]
2026-05-18 Silkscreen minor additions
    [c5_adapter.kicad_pcb]
2026-05-27 Updated 3D models & photos
    [Bottom Case.3mf, Bottom Case.stl, Top Case.3mf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]
2026-06-05 Updated pcb image
2026-06-16 Modified silkscreen markings
    [ESP32-Bus-Pirate-Dock.kicad_sch, c5_adapter.kicad_pcb]
2026-06-16 Inverted port writing
    [c5_adapter.kicad_pcb]
2026-07-25 Renamed project files with new name
    [ESP32-Bit-Pirate-Dock.kicad_pro.kicad_pcb, ESP32-Bit-Pirate-Dock.kicad_pro.kicad_sch, ESP32-Bus-Pirate-Dock.kicad_sch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]
2026-07-29 Added a link to purchase the Dock from PCBWay
2026-07-31 Updated enclosure
    [Bottom Case.3mf, Bottom Case.step, Top Case.3mf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]
2026-08-03 Changed stackup to 2 layers
    [c5_adapter.kicad_pcb, c5_adapter.kicad_sch]
2026-08-03 Fixed file names & added logo library
    [ESP32-Bit-Pirate-Dock.kicad_pcb, ESP32-Bit-Pirate-Dock.kicad_pro.kicad_sch, ESP32-Bit-Pirate-Dock.kicad_sch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]
2026-08-09 Added flash-adapter template
    [flash_adapter.kicad_pcb, flash_adapter.kicad_sch]
2026-08-13 Initial commit of T190_adapteur
    [T190_adapter-B_Cu.gbr, T190_adapter-B_Mask.gbr, T190_adapter-B_Paste.gbr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]
2026-08-13 Added a template to ease creating new adapters
    [templateAdapters.kicad_pcb, templateAdapters.kicad_sch]
2026-08-13 Added an adapter for the Heltec Wifi LoRa V4
    [wifilorav4_adapter-B_Cu.gbr, wifilorav4_adapter-B_Mask.gbr, wifilorav4_adapter-B_Paste.gbr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]
2026-08-14 Updated flash adapter
    [flash_adapter.kicad_pcb, flash_adapter.kicad_sch]
2026-08-14 Added M5STACK Stamp S3 adapter
    Added M5STACK Stamp S3 adapter
    [stamps3_adapter-B_Cu.gbr, stamps3_adapter-B_Mask.gbr, stamps3_adapter-B_Paste.gbr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]
2026-08-16 Added separate CS#
    [flash_adapter.kicad_pcb, flash_adapter.kicad_sch]
2026-08-16 Finished routing
    [flash_adapter.kicad_pcb, flash_adapter.kicad_sch]
2026-08-16 Re-organized adapters per categories
    [TLV6700DDCR.stp, c5_adapter.kicad_pcb, c5_adapter.kicad_sch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]
2026-08-16 Rename project from ESP32-Bit-Pirate-Dock to ESP32-Bit-Pirate-Hardware
2026-08-24 Initial commit of MCU adapter for M5STACK StickS3
    [sticks3_adapter-B_Cu.gbr, sticks3_adapter-B_Mask.gbr, sticks3_adapter-B_Paste.gbr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]
2026-08-24 Initial commit of MCU adapter for M5STACK AtomS3-lite
    Initial commit of MCU adapter for M5STACK AtomS3-lite
    [atoms3lite_adapter-B_Cu.gbr, atoms3lite_adapter-B_Mask.gbr, atoms3lite_adapter-B_Paste.gbr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]
2026-08-25 Updated adapters with USB logo
    Added an USB logo to ensure the card is inserted the right way up.
    Added an USB logo in the logo library
    Updated the gerber files
    [T190_adapter-B_Cu.gbr, T190_adapter-B_Mask.gbr, T190_adapter-B_Paste.gbr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]
2026-08-25 First commit of XIAOS3 adapter
    [xiaos3_adapter-B_Cu.gbr, xiaos3_adapter-B_Mask.gbr, xiaos3_adapter-B_Paste.gbr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]
